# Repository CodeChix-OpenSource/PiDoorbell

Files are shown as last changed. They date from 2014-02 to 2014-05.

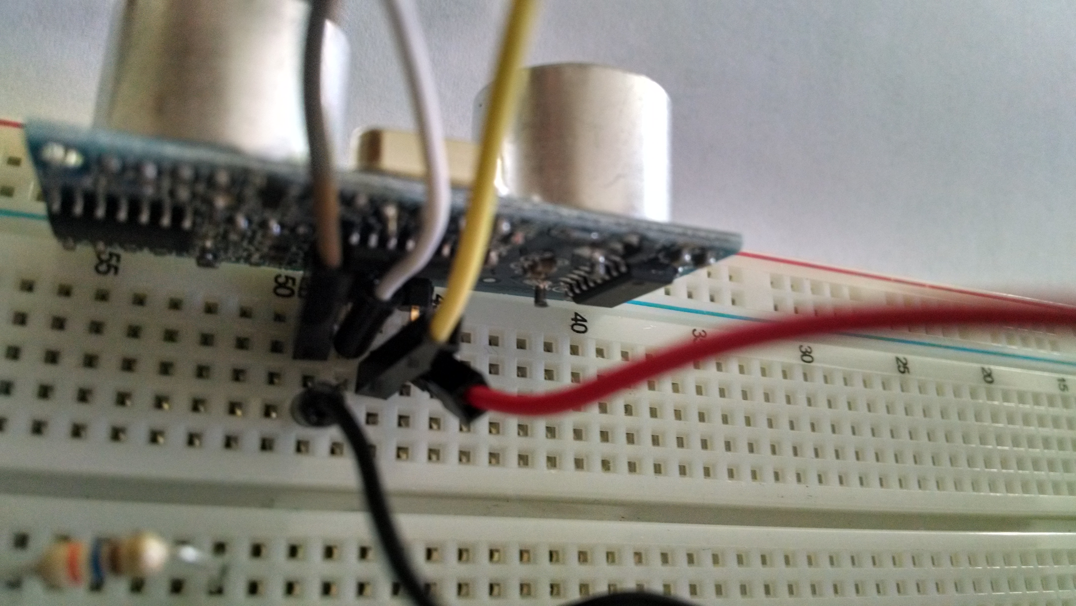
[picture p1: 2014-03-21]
Docs/sensor-wiring-closeup1.jpg

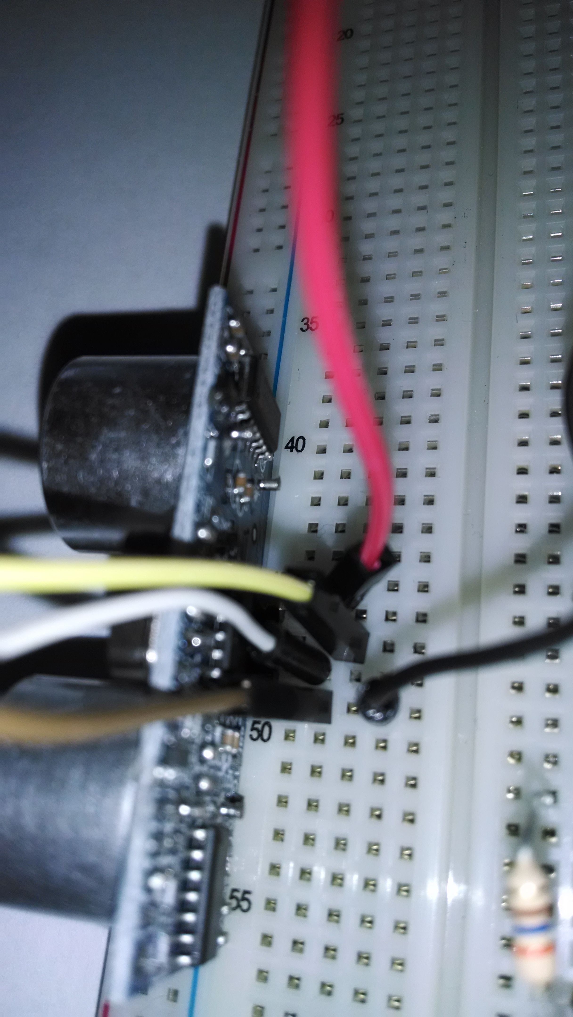
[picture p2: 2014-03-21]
Docs/sensor-wiring-closeup2.jpg

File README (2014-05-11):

**
************************************************************************************
**      CodeChix PiDoorbell - Home Automation with RaspberryPi using GPIO
**      codechix.org - May the code be with you...
**              2013-2014
************************************************************************************
**
** License:       	GPL v2
** Version:        	1.0
** Project/Library:	PiDoorbell
** Description:    	Top level README - individual subdirs
**                 	might also have their own README files
** Assumptions:    	You know Python and Linux basics. And you like to fiddle with hardware.
** Testing:        	Limited - needs lots of testing
** Authors:        	Rupa Dachere, Akkana Peck, Deepa Dhurka, Serpil Bayraktar
**
** Main Contact:   rupa@codechix.org
** Alt. Contact:   organizers@codechix.org
**
** Additional acknowledgements:  Akkana Peck - modifications to the HC_SR04.py script
**					for averaging of sensor readings, creation of
**					piphoto.py to support PiCamera module and 
**					modularize USB Webcam code from 
**					pidoorbell-recognizer-gpio.py
**				 Deepa Karnad Dhurka, Serpil Bayraktar, Rupa Dachere: 
**					For FAQ's
**				 Rupa Dachere, Akkana Peck, Deepa Dhurka:
**					Handouts &  Presentation slides
***********************************************************************************
**

This is PiDoorbell version 3.0
==============================
Version 1.0 - Supports photos with Arduino
Version 2.0 - Supports video/audio clip with Arduino
Version 3.0 - Supports GPIO without Arduino - specifically for 2014 tutorial/workshop

Copyright: CodeChix 2013-2014
==============================
PiDoorbell was created by Rupa Dachere in January 2013 and went through
several revisions (v1-3).  This is a live project and is subject to random
updates with new features and bugfixes.

License information
=====================
PiDoorbell license: GPL v2

What’s new in this release?
=====================
This is version 3.0 which removes the reliance on the Arduino Uno R3 and 
connects the proximity sensor directly to the RaspberryPi via GPIO.  It
captures photos as well as video/audio clips.

Documentation
=====================

For the tutorial, take a look at the "Docs" dir/folder.

What software you get and what you need to create
--------------------------------------------------

1. What you get
 	
	You will get the PiDoorbell code that runs on the RaspberryPi and
	connects to the proximity sensor and USB camera so that you can take
	photos or video/audio clips.  This includes
		pidoorbell-recognizer-gpio.py - main code for detection, notification
		send-notifications.py - code to send tweet, sms etc.
		sms_auth_info.py - authentication keys and tokens for Twilio, Twitter, Dropbox
		dropbox_uploader.sh - script to upload photo/video to Dropbox
		dropbox_token.txt - file containing dropbox uploader tokens
		HC_SR04.py - standalone script to read sensor data
                piphoto.py - module to handle still photos via USB or RPi camera

2. What you will need to create/modify

	(a) In order for notifications to be tweeted/sms'd as well as uploading
		of photos/videos, you will need to create accounts on Twitter, Twilio
		and Dropbox.
		You will need to get your API keys and tokens/secrets from each of these services and modify
		the file called "sms_auth_info.py".  This should be in the same dir/folder as (1).
		If you want to use any other service/API, you will need to put the authentication
		tokens and secrets in this file.  Although the filename might indicate sms content, this
		file holds information on all services.  I might change the filename at some point if this
		turns out to be a bit of a stumbling block for people.

	(b) You will also need to create a directory to store your video/audio clips to upload
		to Dropbox.  Do:
		"mkdir -p dropbox-pidoorbell; chmod 744 dropbox-pidoorbell"

        (c) Download the Dropbox Python SDK and install it.  This is used by the dropbox_uploader.sh
		script to upload and share the file/url.
		"curl "https://raw.github.com/andreafabrizi/Dropbox-Uploader/master/dropbox_uploader.sh" -o dropbox_uploader.sh"
		chmod 744 dropbox_uploader.sh

	(d) You will need to get your Dropbox token and add it as the first and only line
		in the following file.  This should be in the same dir/folder as (1).
		dropbox_token.txt.  When you run the dropbox_uploader.sh script, you will
		get directions on how to get this info and add it to this file.

How to run PiDoorbell from the command line
--------------------------------------------

Assuming you've cloned the repo and have all necessary packages installed (see Dependencies)
and have read & followed the documentation, you should be able to run pidoorbell as follows:

1. git clone git@github.com:codechix/PiDoorbell.git
 
2. sudo python ./pidoorbell-recognizer-gpio.py -h 
	This will provide you with help on the various options.  They are:
	  -i - Run in interactive mode
	  -latency - Latency in seconds if you want to increase the default of 20s
			to account for crappy wifi/network connectivity
			This is optional.
	  -pic_mode - Required field. Specify whether you want to take a Video Clip (1) or Photo (2). Defaults to Photo (2).
			This is optional.
	  -mode - Required field. This is the notification mode. Specify, "sms", "tweet" or "local".  The "local" mode will
			not use services like Twitter, Dropbox or Twilio.	

3. If you want to adjust the latency to account for slow bandwidth when uploading
	to Dropbox, append the latency value to the end of the command like:

   	"sudo python ./pidoorbell-recognizer-gpio.py -i -latency <latency_value> -pic_mode <1 or 2> -mode <sms or tweet or local>"

   	Note that the default latency is 20 seconds 

4. If you want to specify the picture mode for a video clip of 10 secs [1] or a
	snapshot/Photo [2], append the pic_mode value to the end of the command like:

   	"sudo python ./pidoorbell-recognizer-gpio.py -i -pic_mode <1 or 2> -mode <sms or tweet or local>"

   	Note that the default pic_mode is Photo (2).  Video Clip = 1.

NOTE: This code has not been tested in non-interactive mode so bugs may exist.

Web sites
==========
https://github.com/codechix/pidoorbell
http://codechix.github.io/PiDoorbell - web page

Bug report
==========

1. There is a bug with the sequential count (noise tolerance)
	where the count isn't tracked
2. Never tested in non-interactive mode

Supported systems
==========
Wheezy Raspbian - any release since Dec. 2012
USB camera - Logitech c270, c210
HC-SR04 sonar proximity sensor
Dropbox, Twilio, Twitter

Dependencies
==========

1. sudo apt-get install pip pyserial python-rpi.gpio git
2. Create Dropbox account. Download and Install Dropbox Python SDK (1.5.1 and up)
	https://www.dropbox.com/developers/core/sdks/python
3. Create Twilio account and save account ID and authentication keys in sm_auth_info.py
	Download & install Twilio SDK: http://twilio.com/docs/libraries
4. Create Twitter account. Download & Install python-twitter package - https://code.google.com/p/python-twitter/
	- python setup.py build
        - python setup.py install
    	- Test it: python setup.py test  or python twitter_test.py	
5. For photos, PiDoorbell uses fswebcam (should already be installed) or uvccapture
6. Download dropbox_uploader.sh sript - https://github.com/andreafabrizi/Dropbox-Uploader. 
      Please give him some money - he's done a great job.
   Run: curl "https://raw.github.com/andreafabrizi/Dropbox-Uploader/master/dropbox_uploader.sh" -o dropbox_uploader.sh
   Run: chmod 744 dropbox_uploader.sh
7. For video/audio, use ffmpeg (you can also try pyffmpeg - I haven't tried it).
8. Download and compile ffmpeg to capture video clips. I couldn't get avconf to work.: 
    	cd /usr/src/
    	git clone git://source.ffmpeg.org/ffmpeg.git
    	cd ffmpeg      
    	./configure --enable-shared --enable-gpl --prefix=/usr --enable-nonfree --enable-libmp3lame --enable-libfaac --enable-libx264 --enable-version3 --disable-mmx
    	make
    	make install

ToDo
==========
1. Documentation on how to setup and run on Windows 
2. Web-ize configuration and running PiDoorbell from a GUI
3. Fix bugs
4. Audio notification to visitor when they are detected - welcome message
5. Two-way video/audio
6. PiDoorbell Mobile app 

Distribution structure
==========

1. Main directory with 
	README
	pidoorbell-recognizer-gpio.py 
	send_notifications.py
	sms_auth_info.py - you will have to create this.  See Doc.
	dropbox-uploader.sh
	HC_SRO4.py
	dropbox_token.txt
	Docs/Tutorial
	Docs/*.jpg
	Docs/more stuff to come
	
2. Subdirectories
	dropbox-pidoorbell - stores video/audio clips to upload to Dropbox
	Docs - Additional documentation and tutorial, slides 

Contributors 
==========
All contributors are members of:
CodeChix
http://www.codechix.org/
https://github.com/codechix
https://github.com/rdachere
https://github.com/akkana
https://github.com/deepadhurka
https://github.com/serpilb

Sorted by last name:

Bayraktar, Serpil - serpil@cisco.com
Dachere, Rupa - rupa@codechix.org
Karnad, Deepa - deepa.karnad@gmail.com
Peck, Akkana - akkana@gmail.com

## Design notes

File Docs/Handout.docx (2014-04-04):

**

********************************************************************************

** CodeChix PiDoorbell - Home Automation with RaspberryPi using GPIO

** codechix.org - May the code be with you...

** 2013-2014

********************************************************************************

**

** License: Apache 2.0

** Version: 1.0

** Project/Library: PiDoorbell - Handout for Tutorial

** Description: Akkana Peck & Rupa Dachere's writeup based on notes from

** Rupa Dachere's PiDoorbell CodeChix Hacking sessions

** Recordings and testing information provided by Deepa Dhurka,

** Serpil Bayraktar and Rupa Dachere

** The FAQ text file in the GitHub PiDoorbell/Docs repo has

** exhaustive steps for each section

** Assumptions: You know Python and Linux basics. And you like to fiddle

** with hardware.

** Testing: N/A

**

** Main Contact: rupa@codechix.org

** Alt. Contact: organizers@codechix.org

**

***********************************************************************************

**

Hardware Parts List:

- Raspberry Pi (you provide) and power supply

(preferably 1 amp or better)

* SD card loaded with Raspbian and other required software (see below)

* HC-SR04 ultrasonic rangefinder

* Solderless breadboard

* Jumper wires: 4 male-female, 2 male-male

* Resistors: 1 360 Œ© (or optionally 2), 1 470 Œ©

* LED (optional)

* USB to TTL Serial Cable for Rpi, OR ethernet cable

(for RPi-laptop communication)

Optional:

- Camera for RPi: either USB webcam (Logitech C310 or C270) or

Pi Camera. C310 and Pi Cam have been tested.

* USB wi-fi dongle

* Cell phone (for text alerts)

Software

Installed on the Raspberry Pi:

* Raspbian (Wheezy or comparable distro),

* Pip (python-pip), pyserial, python-rpi.gpio, python-twitter (https://code.google.com/p/python-twitter/),

* git, raspistill, fswebcam, ffmpeg (might have to download and compile from ffmpeg.org)

* Twilio Python SDK (pip install twilio)

* Dropbox Uploader script (https://github.com/andreafabrizi/Dropbox-Uploader)

* PiDoorbell repository, installed via: git clone https://github.com/codechix/PiDoorbell

On your laptop: Some means of communicating with the RPi. Either a program like screen plus drivers for a USB-serial device (most Linux systems and some Mac systems have this already), or a way of using IP masquerading over an ethernet cable.

First step: connect to the Raspberry Pi

Without a monitor and USB keyboard, there are two ways of talking to a Raspberry Pi: over a serial cable, or over ethernet.

Using a serial cable lets you see boot messages and works even when the Pi has a networking problem.

Using ethernet takes more setup, but may be easier on some Macs.

Option 1: Connect with Serial Cable

Linux already comes with a driver that will work for the serial cable.

On Mac, you may need to download and install a driver first. You can get

Them here: http://sourceforge.net/projects/osx-pl2303/

If using Lion or Mountain Lion or later OS X, try this

driver: http://changux.co/osx-installer-to-pl2303-serial-usb-on-osx-lio

Accept all defaults when prompted by the installer.

Now wire up the serial cable as shown.

The black wire goes on the third pin from the corner; the white wire goes

next to that,

and then the green.

DO NOT USE THE RED WIRE!

If you do, the Pi will try to get power from that wire (over the USB)

which conflicts with getting

its power from its micro-USB power plug. Just leave that wire hanging

free.

Once the serial cable is connected to the Pi, plug the USB end into your

laptop.

Then run this command:

Linux: screen /dev/ttyUSB0 115200

Mac: screen /dev/cu.PL<something> 115200

The <something> part (on Mac) will vary, so use the Tab key after PL and

let it autocomplete.

If you have trouble, you might have better luck by running Linux under

VirtualBox/Fusion. Make sure you

select the ‚Äúconnect to Linux‚Äù option when connecting the USB to the

Mac.

To exit screen: C-A C-\ (where C- is Control on Linux, Command on Mac).

You can use any other program you prefer for talking to a serial port:

minicom, etc. The device ID may

be something other than /dev/ttyUSB0, depending on your OS.

Once you have a connection established, you should be able to plug in the

Raspberry Pi's power supply

and see boot messages.

Option 2: Connect with Ethernet Cable

Connect the two ends of the ethernet cable to the Pi and your laptop.

Configure your laptop's ethernet address to be 192.168.2.1/24:

On Linux, type: ifconfig eth0 192.168.2.1/24 up

On Mac, use 'network' settings in 'System Preferences' and configure

Manual IP address

Your Pi has been pre-configured with a static IP address on its ethernet

port. Note the IP address,

then try to log in to your Raspberry Pi using ssh:

ssh pi@<your-pi's-IP-address>

Of course, you can use an ssh client like putty if you prefer.

You can even port-forward X to run remote windows (ssh -X pi@<ip address>)

if you're already

familiar with how to do that, but that's beyond the scope of this

tutorial.

Either Way: Now Set Up Wi-Fi

The Raspberry Pi uses the file /etc/network/interfaces to configure

networking.

You'll need to edit that file as root (using sudo). You can use any editor

you're familiar with,

but if you aren't familiar with any on the Pi, pico is probably the

easiest to work with.

First make a backup of it:

sudo cp /etc/network/interfaces /etc/network/interfaces.sav

Then edit it:

sudo vi /etc/network/interfaces

There should be a stanza for eth0 already there. Leave it in place, go to

the end of the

file (add a blank line if needed), then type one of these, depending on

the conference wi-fi we're using:

Open wi-fi (no password):

iface wlan0 inet dhcp

wireless-essid "network-name-goes-here"

wireless-mode managed

WPA/Secure wi-fi, with password:

auto wlan0

allow-hotplug wlan0

iface wlan0 inet dhcp

wpa-ssid ‚Äúnetwork name‚Äù

wpa-psk ‚Äúpassphrase‚Äù

Save the file and exit the editor. Then, back in the Pi's shell, restart

networking:

sudo service networking stop; sudo service networking start

Now test networking by trying to ping an outsite site:

ping www.codechix.org

If that doesn't work, you may need to stop andstart networking again, or

possibly even reboot.

2. FUN: Using GPIO: Blinking an LED

2a. Wire Power and Ground

You'll be using the Raspberry Pi's GPIO header.

The first step is to wire up power and ground to your breadboard.

On a solderless breadboard, the strips along the edges of the board ‚Äì

labeled with red and

blue ‚Äì are generally used for power (red) and ground (blue).

On the Raspberry Pi's GPIO header, the pin in the corner gives you 5 V

power ‚Äì the power

supply the RP is getting from its power input.

The third pin from the corner, in the outer row, is ground. (There are

several other pins

that can provide ground, if you need more than one. But since we're using

a breadboard that's not a problem.)

Use male-female jumpers the female end of each jumper fits over the Pi's

GPIO pin, and

the male end plugs into the breadboard. If possible, use red for power and

black for ground.

2b. Wire up the LED

An LED has one leg longer than the other. The longer leg should be

connected to power, the shorter

one to ground. But you need a small value resistor in the circuit so you

don't burn out the LED.

Use your 360 Œ© resistor for this. It's the one with red and orange bands.

In the middle part of the breadboard (between the power/ground strips),

each line of 5 is wired together.

So with this wired up, the current flows from the Pi to the red power

strip, to the long pin of the LED,

through the LED, through the resistor, out to the ground (blue) power

strip of the breadboard, and out

to the Pi's ground pin.

If your Pi is plugged in and running, the LED should light up as soon as

you finish connecting the wires.

3. Connect the LED to a pin you can control

It's not much fun to have an LED always on.

So instead of connecting the long pin to the breadboard's power rail,

connect it to pin 18 of the Pi's GPIO header.

The pin numbering on the GPIO header doesn't make any sense, so you should

always check a reference to figure

out which pin is which. And worse, there are two different incompatible

ways of numbering the pins. We'll

be using the ‚ÄúBCM‚Äù numbering system. BCM pin 18 is the 6th pin from

the corner on the outer row.

The LED should be off now. Try running the led.py script. You'll have to

run it as root: only root can

access the Raspberry Pi's GPIO pins.

sudo python led.py

Your LED should start blinking.

You can edit led.py and adjust the sleep times.

GPIO Pin Diagram

Take a look at the diagram showing all the pins on the Raspberry Pi's GPIO

header (PiDoorbell/Docs/rpi-gpio.jpeg).

Warning: some pins may vary between different Pi versions.

Hooking up the sonar rangefinder

The HC-SR04 distance sensor emits a sound pulse, then measures the time it

takes for the sound to return.

Same principle as bats, dolphins or submarines.

The HC-SR04 has 4 pins. If you point the sonar horns away from you, the

pins are, from left to right:

Gnd (ground), Echo, Trigger, VCC (5 V power).

We'll connect power and ground, and wire Trigger to BCM pin 23, Echo to

pin 24. Those are the 5th and

6th pins from the audio connector end of the GPIO header on the outer row.

There's one snag: the HC-SR04 runs on 5V, while the Raspberry Pi's GPIO

pins can only handle 3V

(even though it has a 5V power pin). We can compensate for that by using

two resistors as a

‚Äúvoltage divider‚Äù to convert 5V to a level the Pi can handle.

Remember, your 360 Œ© resistor is the one with the orange and blue band.

Try not to get the resistors

backwards, and be sure to connect the 470 Œ© to ground, not power. Too

much voltage on a GPIO pin could

potentially damage your Pi!

Controlling the Rangefinder

To control the HC-SR04, we need to turn the Trigger line high briefly,

then turn it low again. The Echo line goes low. When the sound pulse

returns, the Echo line goes high. So we just need to time how long it takes to

go from low to high.

The HC_SR04.py script does just that. When you have everything wired up,

run it as root to see if everything's

working:

sudo python HC_SR04.py

If everything's okay, you'll see it print repeated lines measuring the

distance in front of it. Try putting

your hand or some other object in front of it and see if the distance

changes.

If you don't see repeated printouts, double-check your wiring. It's

amazingly easy to find yourself one pin off,

or with the Trigger and Echo pins reversed.

Once all the rangefinders are working, we can move on to the real

PiDoorbell logic, in pidoorbell-recognizer-gpio.py.

PiDoorbell Recognizer Script

pidoorbell-recognizer-gpio.py is the main script that incorporates the

sensor, camera (photo + video),

uploading of files and notifications in the form of SMS and Tweets.

It needs to be run as root (because it needs access to GPIO). It can take

several arguments:

pidoorbell-recognizer-gpio.py -h will list them all.

For initial testing, run it like this:

sudo python pidoorbell-recognizer-gpio.py -i -local

-i specifies interactive mode, so you can see verbose messages about what

it's doing. -local keeps it

from using any web services while you're still getting everything hooked

up.

In interactive mode, you should see a steady stream of messages as it

reads distances from the rangefinder.

Try putting your hand or another object in front of the sensor to trigger

it.

By default, the script considers anything from 0 to 30 inches to be within

its target range, and an object has

to remain there for at least 5 seconds before it reacts. These values are

set near the beginning of the script

and are easy to change.

Additional flags that pidoorbell-recognizer-gpio.py supports are:

-latency specifies the time the script waits for photos/videos to be

uploaded to Dropbox. Default is 20s.

You might need to tweak this depending on network latency.

-pic_mode specifies whether to take a video (1) or photo (2). Default:

photo(2).

-mode specifies the notification service to use: "sms" or "tweet" or

"all". Default: "all".

Taking photos or video of your visitors

The recognizer can take a photo if you have a camera on your Raspberry Pi.

That can be either a USB webcam

that works with fswebcam and ffmpeg, or the Raspberry Pi camera module

attached to your Pi.

Ffmpeg and fswebcam are optional software, not installed by default, so

they need to be installed:

apt-get install fswebcam libv4l-0 v4l-utils

When capturing video, ffmpeg is used.

apt-get install ffmpeg

You might need to compile from source: http://ffmpeg.org

RaspberryPi Camera Module

The Pi camera module doesn't use the normal Linux video framework, so it

needs its own programs: raspistill

and raspivid (which should already be installed as part of package

libraspberrypi-bin), or, ideally, a Python

module called picamera which isn't installed by default:

apt-get install python-picamera

By default, the recognizer will try to take a still photo using fswebcam

if it finds a USB camera, or using the

pi camera module if one is installed. With a USB camera, you can shoot a

10-second video instead (video isn't

supported yet for the pi camera) by passing -pic_mode 1 as an argument to pidoorbell-recognizer-gpio.py.

These photos should be created in the dropbox-pidoorbell subdirectory of

your source directory (where you're

running the script). You may need to create that directory.

Adding Dropbox, Twilio, Twitter

Install the dropbox api: pip install dropbox

Open an account at https://www.dropbox.com/home

Get your API Key and Secret at:

https://www.dropbox.com/developers/apply?cont=/developers/apps

You can use an App Name like pidoorbell-yourname, or whatever you like.

Run dropbox_uploader.sh. You will be asked your app key and secret.

Now test the uploader:

$ ./dropbox_uploader.sh

# App key:

<copy here from the website>

# App secret:

<copy here from the website>

# Permission type, App folder or Full Dropbox [a/f]: a

> Token request... OK

Then open the following URL in your browser, and allow Dropbox Uploader

to access your DropBox folder:

https://www2.dropbox.com/1/oauth/authorize?oauth_token=8NGlM1Cj8205nC5w

(this is a sample - you will receive a different URL for authentication

when the script runs.)

Twilio

Install Twilio SDK on the Rpi: pip install twilio

Open an account at https://www.twilio.com

Your account SID and TOKEN are in your Account Settings

ACCOUNT SID <>

AUTH TOKEN <>

Update PiDoorbell/sms_auth_info.py file with Twilio, Dropbox, and Twitter account info.

It should look like:

# Twilio authentication credentials

# The values should be in double quotes, i.e., "xyz"

account_sid = <Your Twilio account secure ID>

auth_token = <Your Twilio authentication token>

# Dropbox app key and secret from the Dropbox dev site

# The values should be in single quotes, i.e., 'xyz'

DB_APP_KEY = <Your Dropbox application key>

DB_APP_SECRET = <Your Dropbox application secret>

DB_ACCESS_TYPE = 'app_folder'

#Twitter authentication credentials

# The values should be in singl quotes, i.e., 'xyz'

twitter_auth_key = <Your Twitter authentication key>

twitter_auth_secret = <Your Twitter authentication secret>

twitter_access_key = <Your Twitter access key>

twitter_access_secret = <Your Twitter access secret>

Putting it all together

With Dropbox and Twilio all set up, run the PiDoorbell code:

pi@raspberrypi ~ $ sudo python pidoorbell-recognizer-gpio.py -i -mode sms

Then put your hand or an object in front of the sensor ‚Äì you should see

messages like:

****** DETECTED AN OBJECT AT -- 9.44145122999 -- INCHES ******

Then it should take a photo (if you have a camera), upload it to Dropbox,

and send you an SMS!

Example output:

pi@raspberrypi ~/pycon2014/pidoorbell $ sudo python pidoorbell-recognizer-

gpio.py -i -mode sms

latency is 20 pic_mode is 2 local_mode is False notification mode is

sms

206.71170739

Distance: 206.7 inches

206.725658952

Distance: 138.9 inches

138.930726795

Distance: 3.6 inches

3.5506725086

****** DETECTED AN OBJECT AT -- 3.5506725086 -- INCHES ******

Distance: 3.4 inches

3.4369136191

****** DETECTED AN OBJECT AT -- 3.4369136191 -- INCHES ******

Distance: 3.8 inches

3.7873124627

****** DETECTED AN OBJECT AT -- 3.7873124627 -- INCHES ******

Distance: 3.4 inches

3.39881512309

****** DETECTED AN OBJECT AT -- 3.39881512309 -- INCHES ******

Distance: 3.4 inches

3.36500941536

****** DETECTED AN OBJECT AT -- 3.36500941536 -- INCHES ******

Taking photo with fswebcam ...

--- Opening /dev/video0...

Trying source module v4l2...

/dev/video0 opened.

No input was specified, using the first.

--- Capturing frame...

Corrupt JPEG data: 3 extraneous bytes before marker 0xd7

Captured frame in 0.00 seconds.

--- Processing captured image...

Writing JPEG image to './dropbox-pidoorbell/visitor-photo-2014:4:3-19:51.jpg'.

************************** UPLOADING TO DROPBOX: ************************

latency is 20

- Uploading "/home/pi/pycon2014/pidoorbell/dropbox-pidoorbell/visitor-

photo-2014:4:3-19:51.jpg" to "/visitor-photo-2014:4:3-19:51.jpg"... DONE

************************ SENDING SMS WITH URL:

https://www.dropbox.com/s/4vhv709udzm2zyn/

visitor-photo-2014%3A4%3A3-19%3A51.jpg

*************************

Appendix: References and Thanks

This handout, all the code, slides, and other materials for this workshop

are available on GitHub:

https://github.com/codechix/PiDoorbell.

This tutorial is run by members of Bay Area CodeChix, a nonprofit

organization for educating, mentoring and promoting women engineers and

developers: http://codechix.org

A big thank-you to our volunteer Teaching Assistants, without whom we

could not have done this tutorial:

Deepa Karnad Dhurka (Networking/Testing/FAQ/Circuit), Serpil Bayraktar (SD

card prep/Testing/Recording Steps), Lyz Krumbach (Testing) and Stuart

Easson (Testing).

And thanks to the Python Software Foundation, which provided a grant for

the hardware kits and this great conference in the first place!

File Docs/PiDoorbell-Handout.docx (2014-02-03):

PiDoorbell Tutorial Handout

Rupa Dachere (rupa@codechix.org)

Akkana Peck (akkana@shallowsky.com)

April 9, 2014, 1p - 4p

PyCon Montreal

## Hardware Parts List (check your bagged kits to make sure you have everything)

Grab this from the emails with PyCon

A photo of one of the bagged kits

## Software List (already on your SD card, but here are URLs and details)

Handout

Code for Pidoorbell - picture of directory structure?

## Part 1 - Hardware, Software, Setup

Setup RaspberryPi (power, SD card, wifi etc)

Connect to laptop and SSH to Rpi successfully

Need photo of the GPIO pins here

Need schematic of which GPIO pins to connect with jumper wires

Setup proximity sensor on breadboard

Need photo of sensor on breadboard

Connect sensor to GPIO pins

Close up photos of connections of jumper wires (make big note about connecting to the right pins)

## Part 2

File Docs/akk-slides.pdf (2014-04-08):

# How do you talk to your Raspberry Pi?

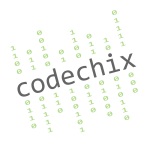
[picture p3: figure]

## Talking to the Pi

- HDMI cable, monitor,
USB keyboard, mouse

## Talking to the Pi

- HDMI cable, monitor,
USB keyboard, mouse

## Talking to the Pi

- HDMI cable, monitor,
USB keyboard, mouse
- Serial cable
- Ethernet

## Serial vs. ethernet

Serial advantages:

- Simple to set up

•Works even when networking doesn't

Ethernet advantages:

- Some Macs have trouble with serial

•Can copy files, route to internet

## Serial setup

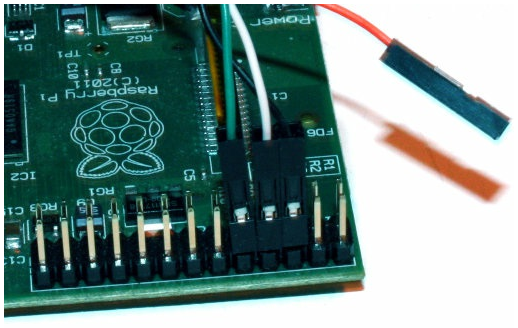
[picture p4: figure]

Leave red wire
free!

Linux: screen /dev/ttyUSB0 115200

Mac: screen /dev/cu.PLXXX 115200

Ethernet ...

# Hardware on the Raspberry Pi

## The good:

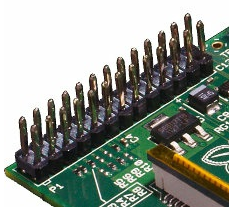
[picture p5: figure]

•Cheap, low power

- That big GPIO connector!

•RPi.GPIO Python module

## The bad :(

•Chaotic pin numbering

- No analog
- Poor PWM support
- ³ volts, not 5

## The GPIO connector

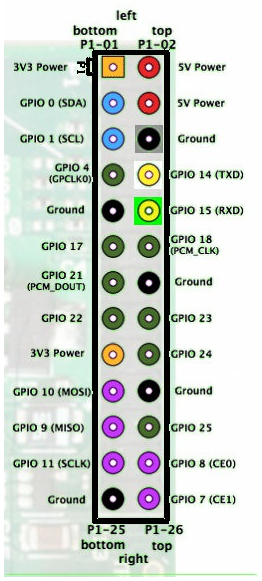
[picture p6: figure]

## Solderless breadboard

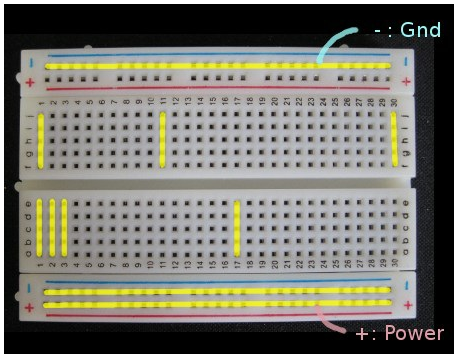
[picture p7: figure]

## Connect power, ground

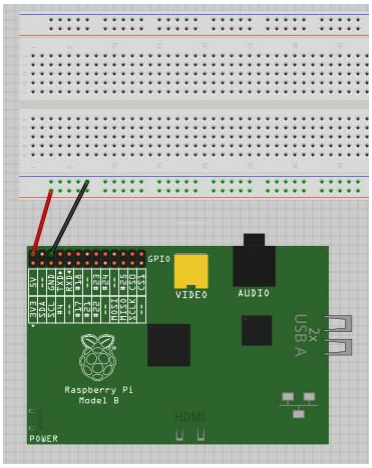
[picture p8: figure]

## Connect an LED

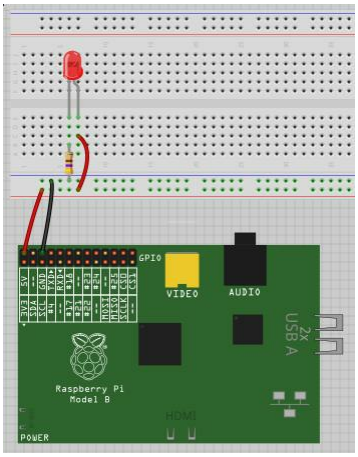
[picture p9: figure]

This LED will stay on (if the RPi is).

## Connect the LED to pin 18

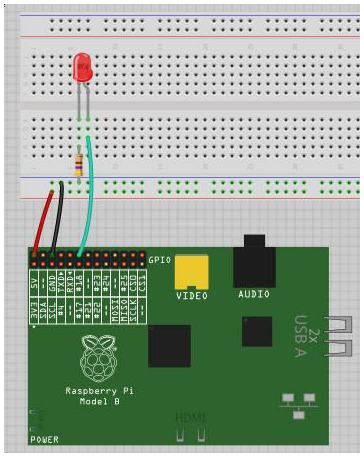
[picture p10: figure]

## Blink an LED on pin 18

import RPi.GPIO as GPIO
import time

GPIO.setmode(GPIO.BCM)

pin = 18

GPIO.setup(pin, GPIO.OUT)

while True:
GPIO.output(pin, 0)
time.sleep(.5)
GPIO.output(pin, 1)
time.sleep(.5)
(This is led.py in the source.)

## BCM vs BOARD numbering

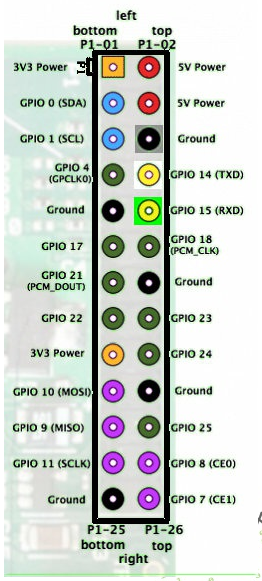
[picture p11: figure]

BCM: functional notation

BOARD: actual pin numbers on the RPi.

BOARD sounds appealing, but doesn't save you from needing GPIO numbers.

## HC-SR04 Sonar Rangefinder

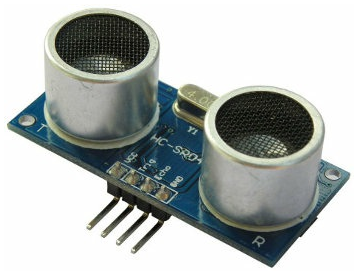
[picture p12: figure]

Emits a pulse of
sound;
times how long the
sound takes to return.

About $5 on Amazon.

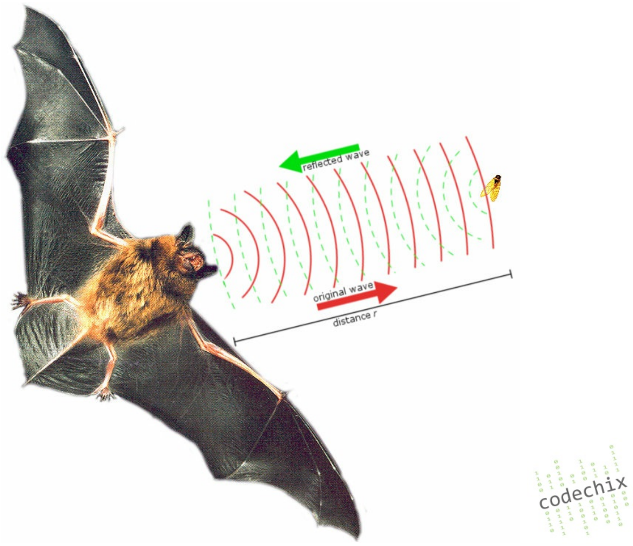
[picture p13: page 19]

## Using the HC-SR04

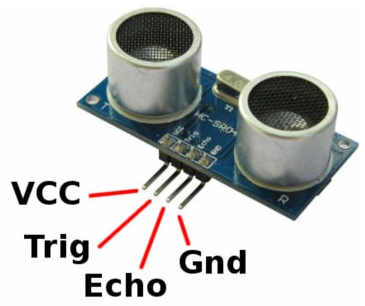
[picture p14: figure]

Write to the Trigger;

read Echo to learn
when the sound pulse
returns.

## One problem:

The HC-SR04 operates on 5 volts.

The Raspberry Pi's GPIO pins can only handle 3 volts or less.

We'll use a voltage divider
(2 resistors) to turn 5V into 3V.

## Connecting the HC-SR04

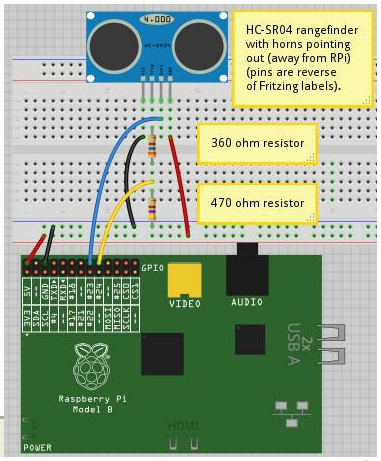
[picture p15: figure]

Be careful of which
resistor goes where!

When ready, test it by
running

sudo python HC_SR04.py

# Running the PiDoorbell app

## Local mode

$ sudo python pidoorbell-recognizer-gpio.py -i -local

Distance: 102.0 inches
102.022406334
Distance: 150.8 inches
150.823360135
Distance: 151.5 inches
151.532743398
Distance: 150.9 inches
150.938192221
Distance: 11.9 inches
11.884047763
** DETECTED AN OBJECT AT -- 11.884047763 -- INCHES ** Distance: 11.8 inches
11.7531177204

Adding networking ...

# Cameras

## USB Webcam

Shows up as /dev/video0

To take a still image: fswebcam

To take a video: ffmpeg or avconv

Packages you'll need:

$ sudo apt-get install fswebcam libv4l v4l-utils ffmpeg

## Raspberry Pi Camera

Shows up as /dev/fb0

To take a still image: raspistill To take a video: raspivid

Or use the picamera package:

$ sudo apt-get install python-picamera

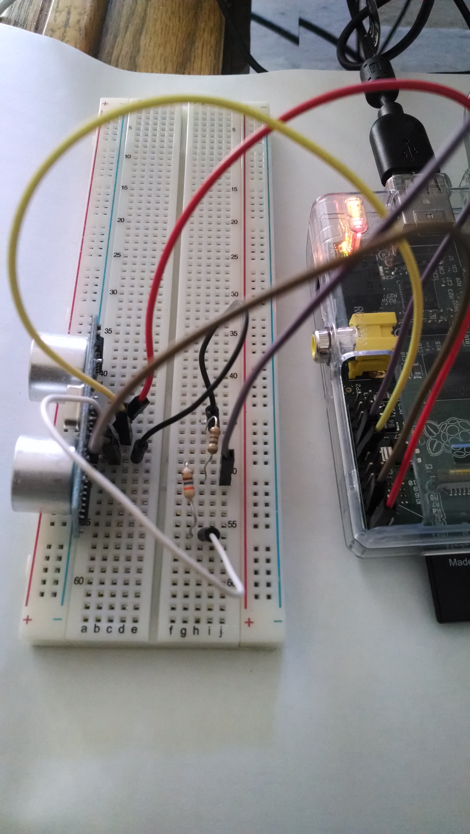
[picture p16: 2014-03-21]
Docs/circuit+rpi-gpio.jpg

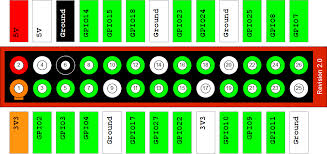
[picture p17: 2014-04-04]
Docs/rpi-gpio.jpeg

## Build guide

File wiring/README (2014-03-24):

Files ending in FZZ are made with Fritzing (fritzing.org).

You can download fritzing parts for the Raspberry Pi from:
https://github.com/adafruit/Fritzing-Library/tree/master/parts
and the HC-SR04 fritzing part from:
http://fritzing.org/projects/hc-sr04-project

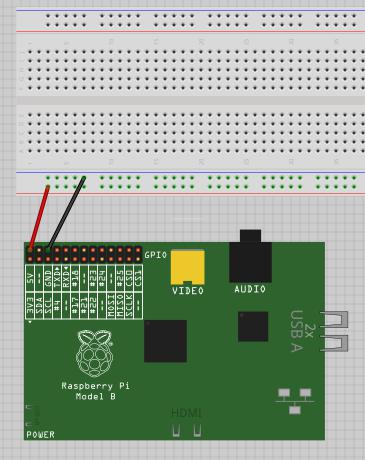
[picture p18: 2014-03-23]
wiring/power.jpg

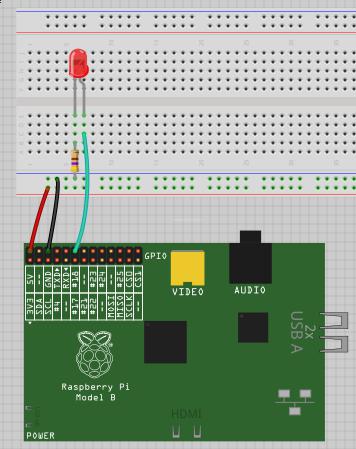
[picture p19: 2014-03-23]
wiring/led-18.jpg

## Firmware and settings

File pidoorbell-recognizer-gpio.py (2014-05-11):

#! /usr/bin/env python

# Copyright (C) 2013-2014 Rupa Dachere <rupa@codechix.org>>
#
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
#  Dependencies:
#	HC_SR04.py, piphoto.py, sms_auth_info.py,
#	dropbox_token.py, dropbox_uploader.sh
#	ffmpeg, fswebcam, raspistill
#
#  Takes photo or video.  Checks to see if USB webcam 
#	or RaspberryPi Camera module is present and automatically
#	uses the correct input device
#	Modifications by Akkana Peck - akkana@gmail.com
#

import sys, threading
sys.path.append("/home/pi/pycon2014/pidoorbell")
from subprocess import call, Popen, PIPE
from time import time, sleep
import datetime, argparse
import RPi.GPIO as GPIO
from HC_SR04 import init_HC_SR04, average_distance
from piphoto import take_still

# bunch of defines to tweak when needed

BASEDIR_FOR_PIDOORBELL_VIDEOS = "./dropbox-pidoorbell/"

MAX_TRIGGER_DISTANCE   = 30   # inches
MIN_TRIGGER_DISTANCE   = 0    # inches
VALID_PIC_THRESHOLD    = 5    # weak attempt at mitigating "noise" (butterfly/moth/damned spiders))
DEFAULT_LATENCY        = 20   # default secs to wait to compensate for network latency/bandwidth
DELAY_BETWEEN_VISITORS = 20   # delay between polling for visitors 

# picture modes - video capture (10 seconds) or photo
VIDEO = 1
PHOTO = 2

FFMPEG_CMD = "ffmpeg -f video4linux2 -s 320x240 -i /dev/video0 -f alsa -ar 22050 -ac 1 \
                 -i hw:1,0 -ab 48k -timelimit 10 ./dropbox-pidoorbell/"

SEND_NOTIFICATIONS_ALL   = "python ./send_notifications.py -m all -u"
SEND_NOTIFICATIONS_SMS   = "python ./send_notifications.py -m sms -u"
SEND_NOTIFICATIONS_TWEET = "python ./send_notifications.py -m tweet -u"

# Progress print stmts for demo's
PRINT_STARTING_VIDEOCLIP = "\n\n************************** STARTING VIDEOCLIP:   ************************ \n\n" 
PRINT_STOPPING_VIDEOCLIP = "\n\n**** ENDING VIDEOCLIP FOR - "
PRINT_UPLOAD_TO_DROPBOX  = "\n\n************************** UPLOADING TO DROPBOX: ************************ \n\n" 

class PiDoorbell_GPIO() :

    def run(self, interactive, latency, pic_mode, local_mode, notify_mode) :

        global BASEDIR_FOR_PIDOORBELL_VIDEOS, \
               MIN_TRIGGER_DISTANCE, MAX_TRIGGER_DISTANCE, \
               BASEPORT_FOR_SENSOR_DATA, BASEPORT_BAUD_RATE

        if not local_mode:
            import sms_auth_info

        valid_pic_count = 0

        try:
            init_HC_SR04()

            while True :
                data = average_distance()
                if not data :
                    continue

                if not interactive :
                    print data
                    continue

                print "Distance: %.1f inches" % data
                print data
                if int(data) <= MIN_TRIGGER_DISTANCE or int(data) >= MAX_TRIGGER_DISTANCE:
                    continue

                # There's an object in the target distance range
                print "******  DETECTED AN OBJECT AT --    ", data ,"-- INCHES ****** "

                valid_pic_count += 1

                if valid_pic_count < VALID_PIC_THRESHOLD:
                    continue

                # We have enough pics:
                # build pidoorbell_filename with date and timestamp
                now = datetime.datetime.now()

                if pic_mode == VIDEO:
                    pidoorbell_filename = "visitor-video-%d:%d:%d-%d:%d.mpg" % \
                        (now.year, now.month, now.day, now.hour, now.minute)
                    #take a video snippet 
                    take_videoclip_cmd = FFMPEG_CMD + pidoorbell_filename

                    print PRINT_STARTING_VIDEOCLIP

                    videoclip_cmd_rc = call(take_videoclip_cmd, shell=True)

                    print PRINT_STOPPING_VIDEOCLIP + pidoorbell_filename

                # default to photo
                else: 
                    pidoorbell_filename = "visitor-photo-%d:%d:%d-%d:%d.jpg" % \
                               (now.year, now.month, now.day, now.hour, now.minute)
                    # take a photo snippet
                    try:
                        take_still(BASEDIR_FOR_PIDOORBELL_VIDEOS+pidoorbell_filename, verbose=True)
                    except SystemError:
                        print "Couldn't take a photo"
                        continue

                #reset valid_pic_count
                valid_pic_count = 0

                if local_mode:
                    print "Local mode: not syncing to the outside world"
                    sleep(DELAY_BETWEEN_VISITORS)
                    continue

                # Not local mode, so proceed with dropbox and sms:
                print PRINT_UPLOAD_TO_DROPBOX

                sync_dropbox_cmd = "./dropbox_uploader.sh upload ./dropbox-pidoorbell/" + \
                    pidoorbell_filename + " "+ pidoorbell_filename
                process = Popen(sync_dropbox_cmd, shell=True)

                ## account for network latency 
                print "latency is %s " % latency
                sleep(float(latency))

                get_link_cmd = "./dropbox_uploader.sh share " + pidoorbell_filename

                p = Popen(get_link_cmd, stdout=PIPE, shell=True)
                (output, err) = p.communicate()

                # Send notifications using both Twilio (USA) and Twitter (worldwide)
                # for demo purposes.  Else, use "-m sms" for SMS, "-m tweet" for TWITTER
                # See definitions section for predefined vars to use (SEND_NOTIFICATIONS_SMS,
                # SEND_NOTIFICATIONS_TWEET)

		if notify_mode == "local":
			break;
		else:
		    if notify_mode == "sms":
                       send_sms_cmd = SEND_NOTIFICATIONS_SMS + output
		    elif notify_mode == "tweet":
                       send_sms_cmd = SEND_NOTIFICATIONS_TWEET + output
		    elif notify_mode == "all":
                       send_sms_cmd = SEND_NOTIFICATIONS_ALL + output

                    sms_url_rc = call(send_sms_cmd, shell=True)

                #sleep for a short while before checking again
                sleep(DELAY_BETWEEN_VISITORS)

                print "Done sleeping  - I'm awake again!!!! "
                continue      

        except KeyboardInterrupt:
            # User pressed CTRL-C: reset GPIO settings.
            print "Cleaning up ..."
            GPIO.cleanup()

if __name__ == '__main__':

    # parse command line arguments to detect whether optional flags are set for
    #   interactive mode - "-i"
    #   latency - "-latency"
    #   picture mode - "-pic_mode"
    #   mode - "sms" or "tweet" "-local" (skip Twilio, Twitter and Dropbox)

    parser = argparse.ArgumentParser()

    parser.add_argument("-i", action="store_true", help="Indicates interactive run mode for PiDoorbell")
    parser.add_argument("-latency", type=int, help="Increase latency to account for wifi/network issues. Default: 20s")
    parser.add_argument("-pic_mode", type=int, choices=[1,2], help="Required field. Specify Video Capture (1) or Photo (2). Default: Photo (2)", required=True)
    parser.add_argument("-mode", help="Required field. Specify 'sms' or 'tweet' or 'local' for Twitter/SMS notifications. For 'local', services like Dropbox, Twitter, Twilio will not be used. Default: All", required=True)

    args = parser.parse_args()
    if args.latency:
        #print "latency is: ", args.latency
        latency = args.latency
    else:
        latency = DEFAULT_LATENCY

    if args.pic_mode:
        #print "picture mode is: ",args.pic_mode
        pic_mode = args.pic_mode
    else:
        pic_mode = PHOTO

    if args.mode:
        #print "notification mode is: ",args.mode

	local_mode = False

        if args.mode == "sms":
            notify_mode = "sms"
        elif args.mode == "tweet":
            notify_mode = "tweet"
        elif args.mode == "local":
	    notify_mode = "local"
            local_mode = True
        else:
            notify_mode = "all"

    print "latency is ", latency, " pic_mode is ", pic_mode, " local_mode is ", local_mode, " notification mode is ", notify_mode

    pidoorbell_gpio = PiDoorbell_GPIO()
    pidoorbell_gpio.run(args.i, latency, pic_mode, local_mode, notify_mode)

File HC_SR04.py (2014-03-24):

#!/usr/bin/env python

# Raspberry Pi driver for the HC-SR04 ultrasonic rangefinder.
# Copyright (C) 2014 Akkana Peck <akkana@shallowsky.com>>
#
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

# Adapted from code by Matt Hawkins of RaspberryPi-Spy.co.uk
# Wire the circuit as shown in
# http://www.raspberrypi-spy.co.uk/2013/01/ultrasonic-distance-measurement-using-python-part-2/
#
#  Modifications:
#
#      Author: Rupa Dachere
#      Date: March 19, 2014
#      Changes: 
#    	    	1. Fixed typo for call to measure_distance_cm()
#		2. Created measure_distance_in() for inches
#		3. Initialized stop in measure_distance_cm() and measure_distance_in()


import RPi.GPIO as GPIO
import time

GPIO_TRIGGER = 23
GPIO_ECHO    = 24

def init_HC_SR04():
    '''Call this once at the beginning of the script
       before measuring any distances.
    '''
    
    # Use BCM instead of physical pin numbering:
    GPIO.setmode(GPIO.BCM)

    # Set trigger and echo pins as output and input
    GPIO.setup(GPIO_TRIGGER, GPIO.OUT)
    GPIO.setup(GPIO_ECHO, GPIO.IN)

    # Initialize trigger to low:
    GPIO.output(GPIO_TRIGGER, False)

def measure_distance_cm():
    '''Measure a single distance, in cemtimeters.
    '''
    GPIO.output(GPIO_TRIGGER, True)
    time.sleep(0.00001)
    GPIO.output(GPIO_TRIGGER, False)
    start = time.time()
    stop = time.time()

    while GPIO.input(GPIO_ECHO) == 0:
        start = time.time()

    while GPIO.input(GPIO_ECHO) == 1:
        stop = time.time()

    # Convert to inches:
    return ((stop - start) * 34300)/2

def measure_distance_in():
    '''Measure a single distance, in inches.
    '''
    GPIO.output(GPIO_TRIGGER, True)
    time.sleep(0.00001)
    GPIO.output(GPIO_TRIGGER, False)
    start = time.time()
    stop = time.time()

    while GPIO.input(GPIO_ECHO) == 0:
        start = time.time()

    while GPIO.input(GPIO_ECHO) == 1:
        stop = time.time()

    #print "In here 8: stop is %d start is %d" % (stop, start)

    # Convert to inches:
    return (((stop - start) * 34300)/2)*0.393701

def average_distance(samples=3):
    tot = 0.0
    for i in xrange(samples):
        tot += measure_distance_in()
        time.sleep(0.1)
    return tot / samples

if __name__ == '__main__':
    try:
        init_HC_SR04()
        while True:
            print "Distance: %.1f inches" % average_distance()
            time.sleep(1)
    except KeyboardInterrupt:
        # User pressed CTRL-C: reset GPIO settings.
        print "Cleaning up ..."
        GPIO.cleanup()

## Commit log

2014-03-04 RPi function to read HC-SR04 sonar rangefinder
2014-03-11 Add a link to the URL with the circuit
2014-03-20 fix bugs to get sensor to work with rpi gpio
    [HC_SR04.py]
2014-03-21 pidoorbell recognizer modifications to support sensor connected to Rpi gpio instead of arduino
2014-03-21 Delete pidoorbell-recognizer.py
    This is the old version which uses the arduino and doesn't belong in this repo. It just makes things confusing.
2014-03-21 first successful circuit with gpio for pidoorbell - can be simplified
2014-03-21 spec out which resistor has red/orange band in pidoorbell.jpg
2014-03-21 simplified circuit to only use 2 male-male jumper wires instead of 3
2014-03-21 more pictures of simplified circuit including close-ups
2014-03-21 Delete pidoorbell-gpio.jpg
    simplified circuit photos replace this one.
2014-03-23 Whitespace changes: fix indentation, use spaces only
    [pidoorbell-recognizer-gpio.py]
2014-03-23 Simple LED blink program
2014-03-23 Wiring diagrams for the various steps of the tutorial
    [led-18.fzz, led-always-on.fzz, power.fzz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]
2014-03-23 minor changes while debugging broken notifications
    [piphoto.py]
2014-03-23 fix bug for taking still photo which broke dropbox/twilio/twitter etc.
    [pidoorbell-recognizer-gpio.py]
2014-03-24 Update to ue the right rangefinder part
    [rangefinder.fzz]
2014-03-30 Add instructions for connecting via ethernet, setting up the wi-fi, and downloading the Mac serial driver
2014-03-30 Sample interfaces and wpa_supplicant.conf for wifi roaming
2014-04-01 Fix some circuit errors for the rangefinder circuit: resistors were mislabeled and on the wrong rangefinder pin
    [rangefinder.fzz]
2014-04-03 Add FAQ about OOM error on camera
2014-04-04 revisions to handout and text/msdoc versions for printing
2014-04-04 pdf for printing for pycon 2014
2014-04-06 Adjust css to match Rupa's slides; remove getting-connected section (Deepa will be covering that); add a little more background about the RPi, hardware and GPIO; add a couple of slides covering camer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
2014-04-07 Switch to green-header style to match Rupa's theme. Split into the sections I'll be covering: communicating with serial, hardware/GPIO, the recognizer, and cameras.
2014-04-08 fixed laptop connector ip address to 192.168.2.1
2014-05-11 bug fixes to incorporate local mode
    [pidoorbell-recognizer-gpio.py]

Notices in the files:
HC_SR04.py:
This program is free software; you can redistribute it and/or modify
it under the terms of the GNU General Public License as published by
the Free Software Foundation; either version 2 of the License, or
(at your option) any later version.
